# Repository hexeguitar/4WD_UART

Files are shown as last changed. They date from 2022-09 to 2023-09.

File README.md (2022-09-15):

# 4WD UART
### CH344Q based quad isolated USB-UART interface with ESP programmer. 
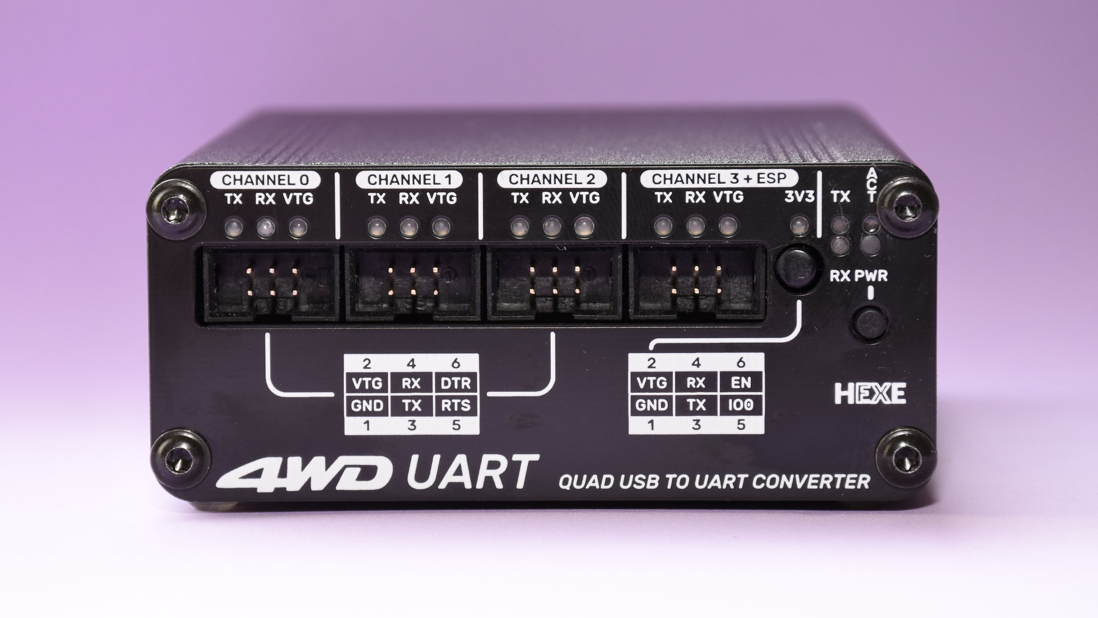
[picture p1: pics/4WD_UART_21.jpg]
 
### Features | Specs 
* 4 fully isolated channels  
  * Channel 0 - 2: classic UART with TX, RX, DTR and RTS signals
  * Channel 3: UART + ESP8266/ESP32 programmer signals (EN + IO0) and isolated 3.3V supply  
* individual TX/RX activity indicators per channel  
* theoretical max baud rate per channel: 6Mbps (tested up to 4.5Mbps on Linux)
* target voltage range: 3V - 5V (required for the isolators)
* USB C for power and data
* optional soft power switch (hold to power on/off) or regular toggle one
* USB inrush current limiter

<table>
  <tr>
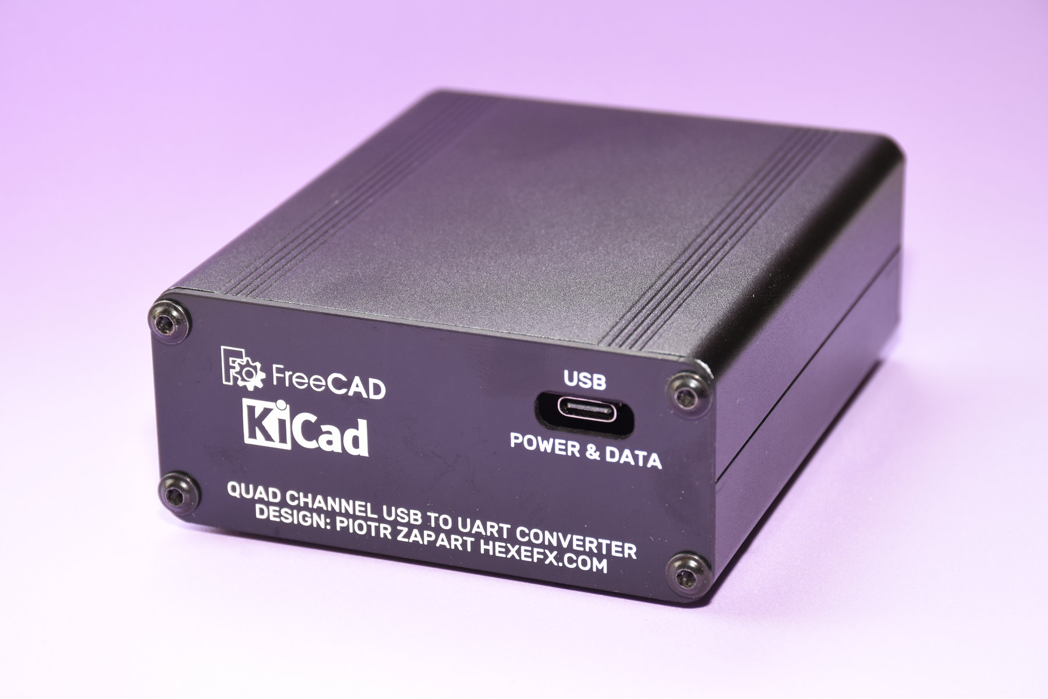
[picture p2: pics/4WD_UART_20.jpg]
rear view
    <td> </td>
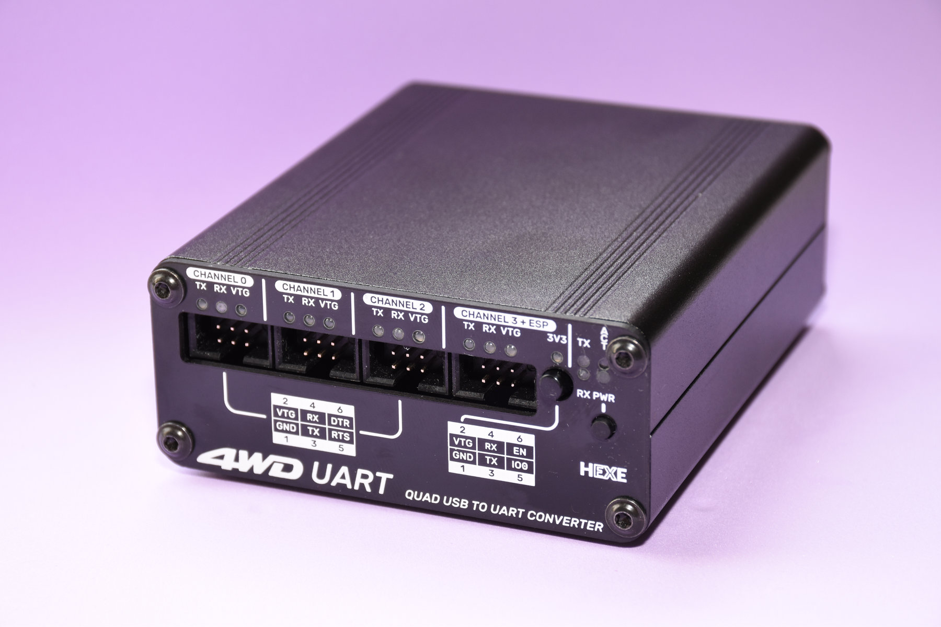
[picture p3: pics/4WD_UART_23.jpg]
4WD UART
    <td> </td>
  </tr>  
</table>  

### Leds  
Per channel:
* TX, RX - activity leds
* VTG - target power presence  

For channel 3:
* 3V3 - internal isolated 3.3V supply enable  

Global:
* TX, RX - global CH344Q activity leds
* ACT - USB enumeration success
* PWR - power indicator

### Electronic design  
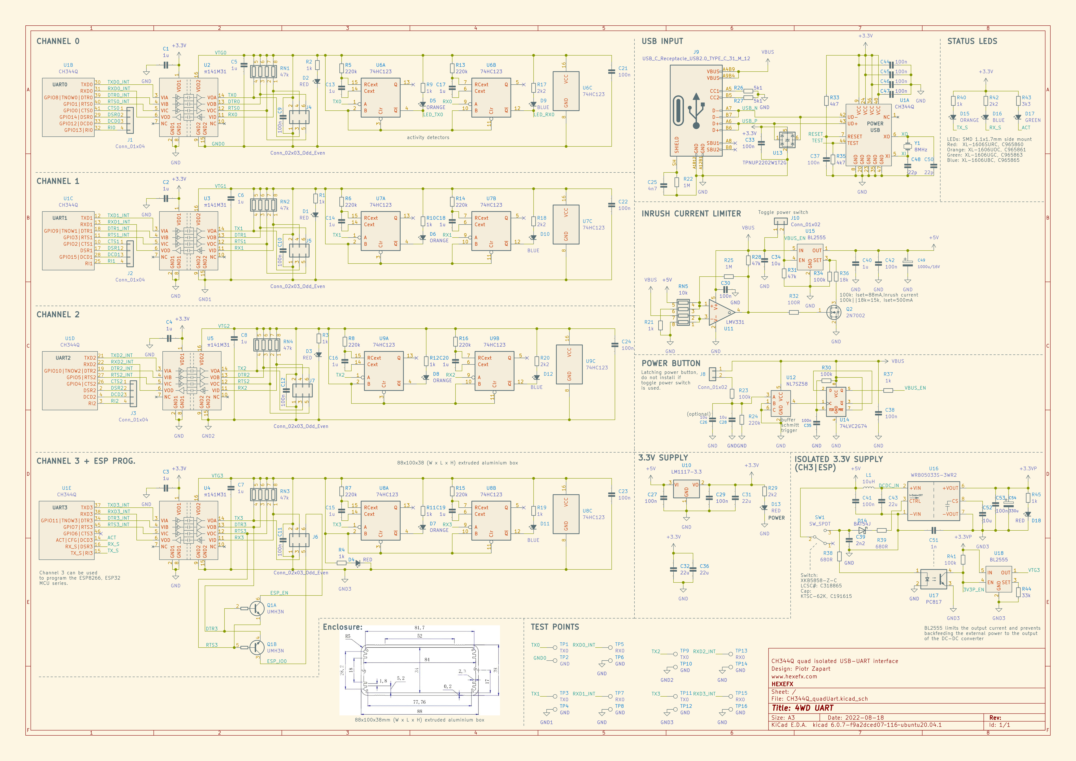
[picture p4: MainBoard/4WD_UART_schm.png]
 
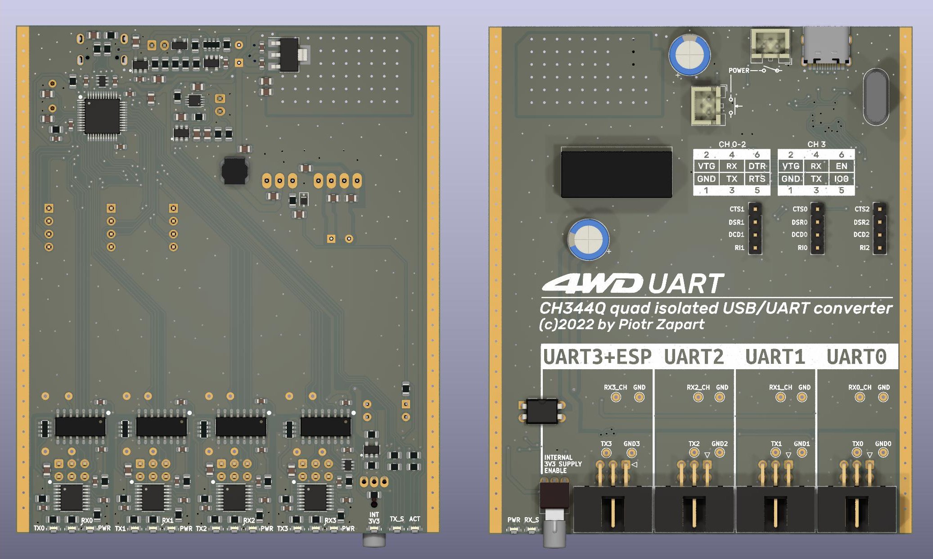
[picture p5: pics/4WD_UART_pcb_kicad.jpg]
 

### Mechanical design  
PCB is designed to slide into an 88x100x38mm aluminium extruded enclosure. Front panel and back panel PCBs replace the original plates.  
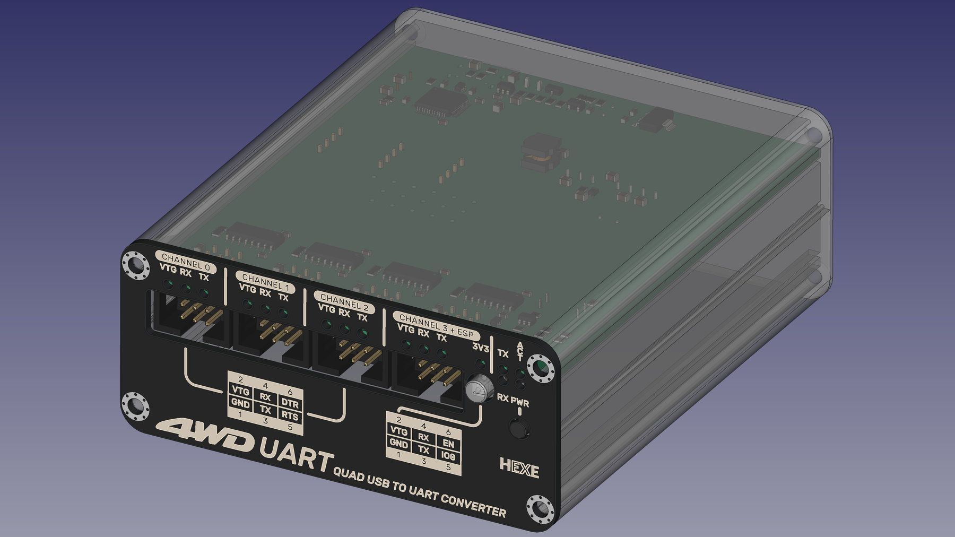
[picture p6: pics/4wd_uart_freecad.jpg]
 
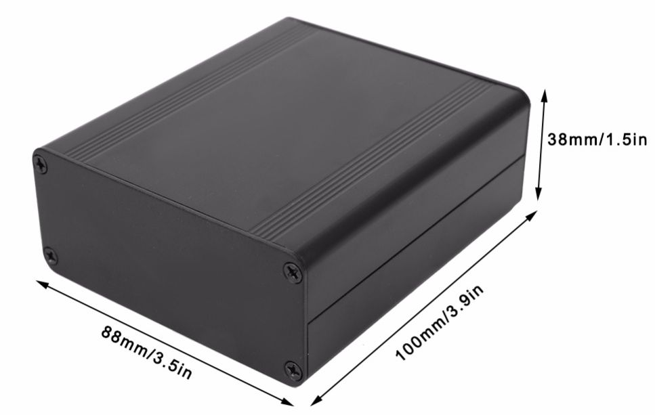
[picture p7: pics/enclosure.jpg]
 

### Front panel  
Front panel is designed to accommodate the version with soft power switch. A normal pushbutton is used, but installed in reverse with terminals bent, as shown on the pic:  
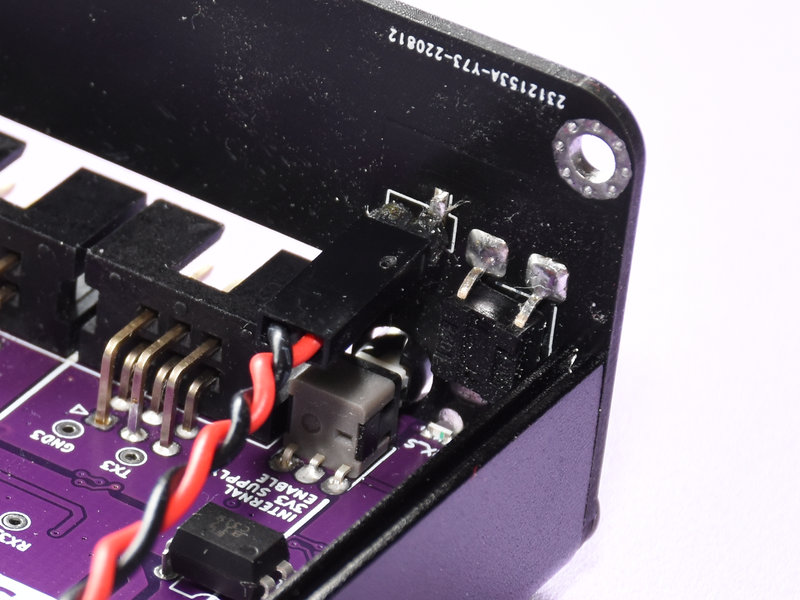
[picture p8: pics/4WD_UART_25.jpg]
  
A single 1x02 0.1" SMD type pin header is used to connect the pushbutton to the main board.  
Light pipes for the leds can be made by pushing a tiny bit of hot glue into the holes.  

### Operation  
For most modern operating systems the device does not require any special drivers and should be detected automatically.  
On Linux 4WD UART is reporting as 4 /dev/TTYACMx devices:  
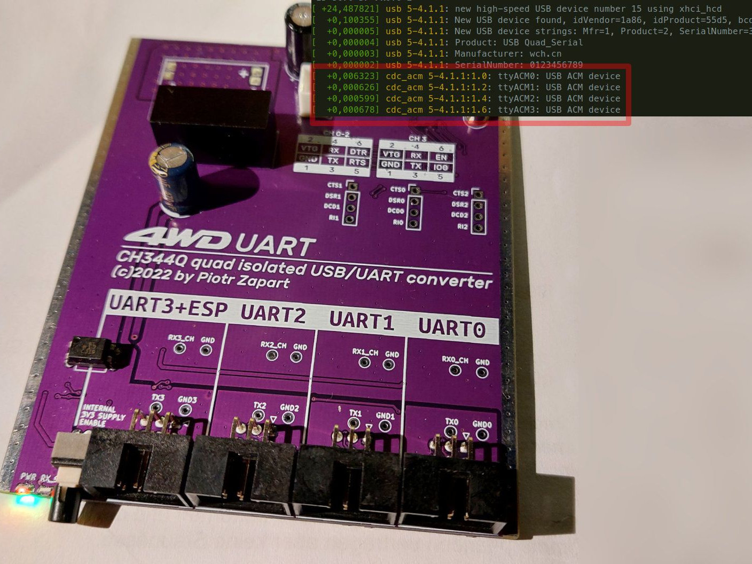
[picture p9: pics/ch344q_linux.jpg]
  

___
## All channels except 3 (if 3V3 is enabled) require external power supply in range from 3V to 5V to operate the output digital isolators and do the level shifting.  

Copyright (c) 2022 by Piotr Zapart  
www.hexefx.com  

## License
  
This work is licensed under a [Creative Commons Attribution-ShareAlike 3.0 International License][cc-by-sa].  

[cc-by-sa]: http://creativecommons.org/licenses/by-sa/3.0/
[cc-by-sa-image]: https://licensebuttons.net/l/by-sa/3.0/88x31.png
[cc-by-sa-shield]: https://img.shields.io/badge/License-CC%20BY--SA%203.0-lightgrey.svg

[main_pic]: pics/4WD_UART_21.jpg "4WD UART front view"
[rear_view]: pics/4WD_UART_20.jpg "rear view"
[iso_view]: pics/4WD_UART_23.jpg "4WD UART"
[schematic]: MainBoard/4WD_UART_schm.png "4WD UART schematic"
[pcb]: pics/4WD_UART_pcb_kicad.jpg "4WD UART pcb"
[mech1]: pics/4wd_uart_freecad.jpg "4WD UART enclosure"
[mech2]: pics/enclosure.jpg "4WD UART enclosure"
[panel1]: pics/4WD_UART_25.jpg "4WD UART enclosure"  
[linux]: pics/ch344q_linux.jpg "4WD UART enclosure"

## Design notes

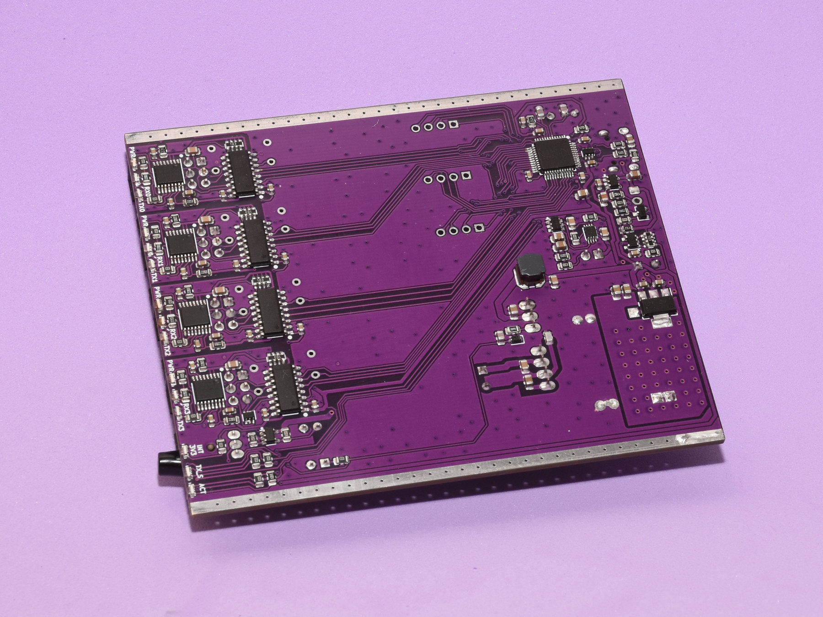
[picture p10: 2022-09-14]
pics/4WD_UART_24.jpg

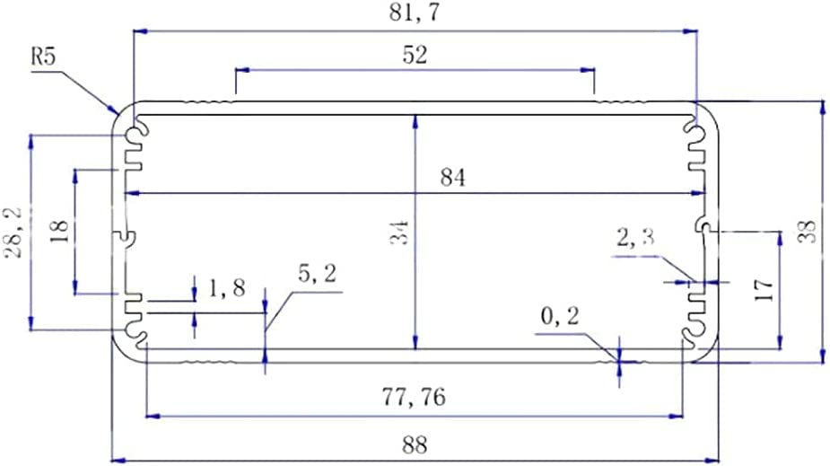
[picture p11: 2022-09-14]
pics/88x100x38_aluBox.jpg

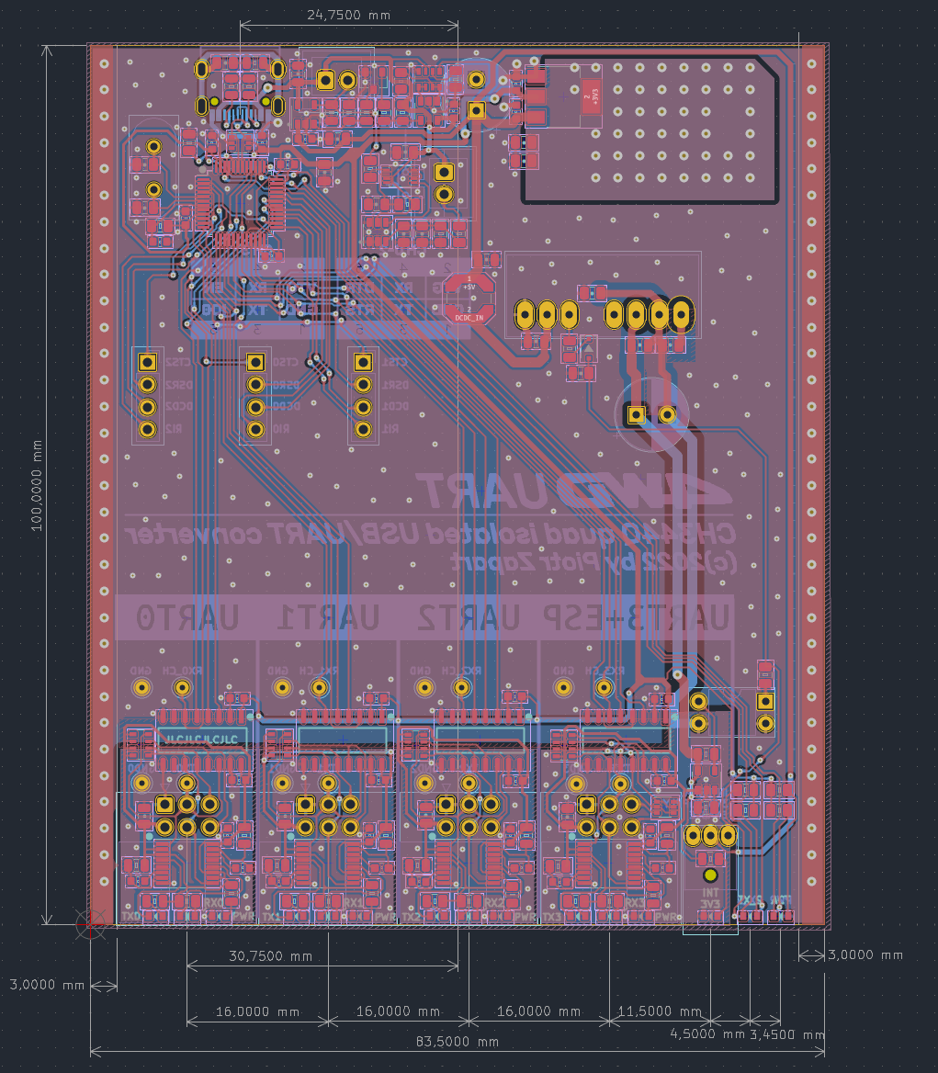
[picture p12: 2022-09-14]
pics/4WD_UART_pcb_dim.png

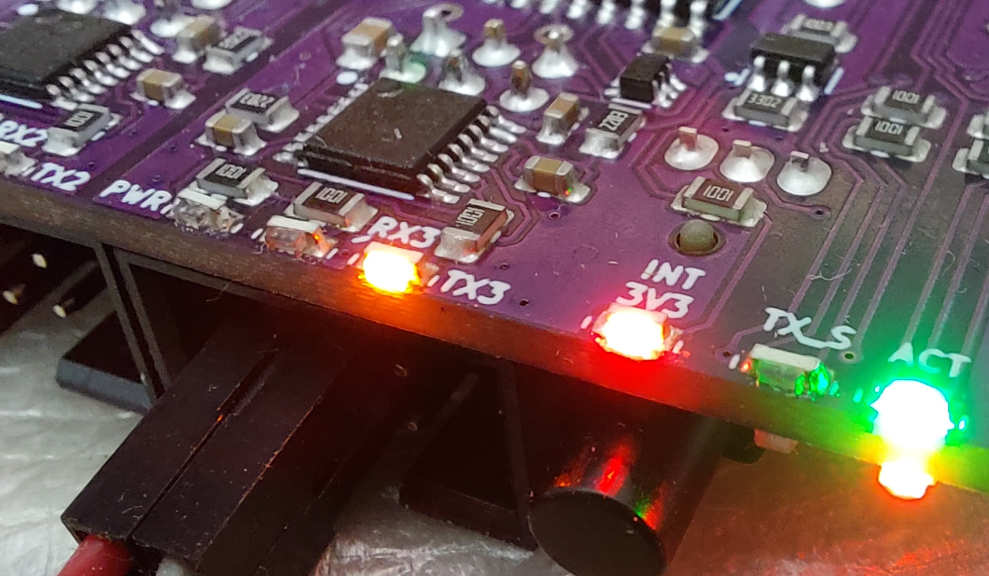
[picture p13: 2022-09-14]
pics/4WD_UART_18.jpg

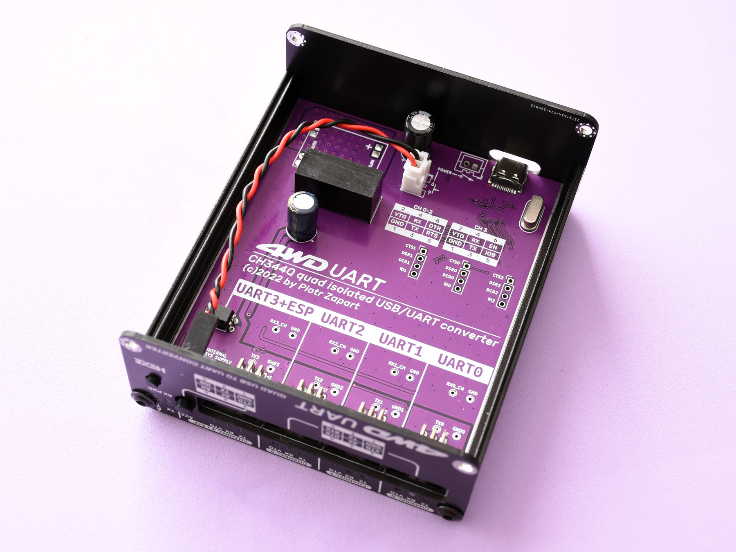
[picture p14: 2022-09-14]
pics/4WD_UART_22.jpg

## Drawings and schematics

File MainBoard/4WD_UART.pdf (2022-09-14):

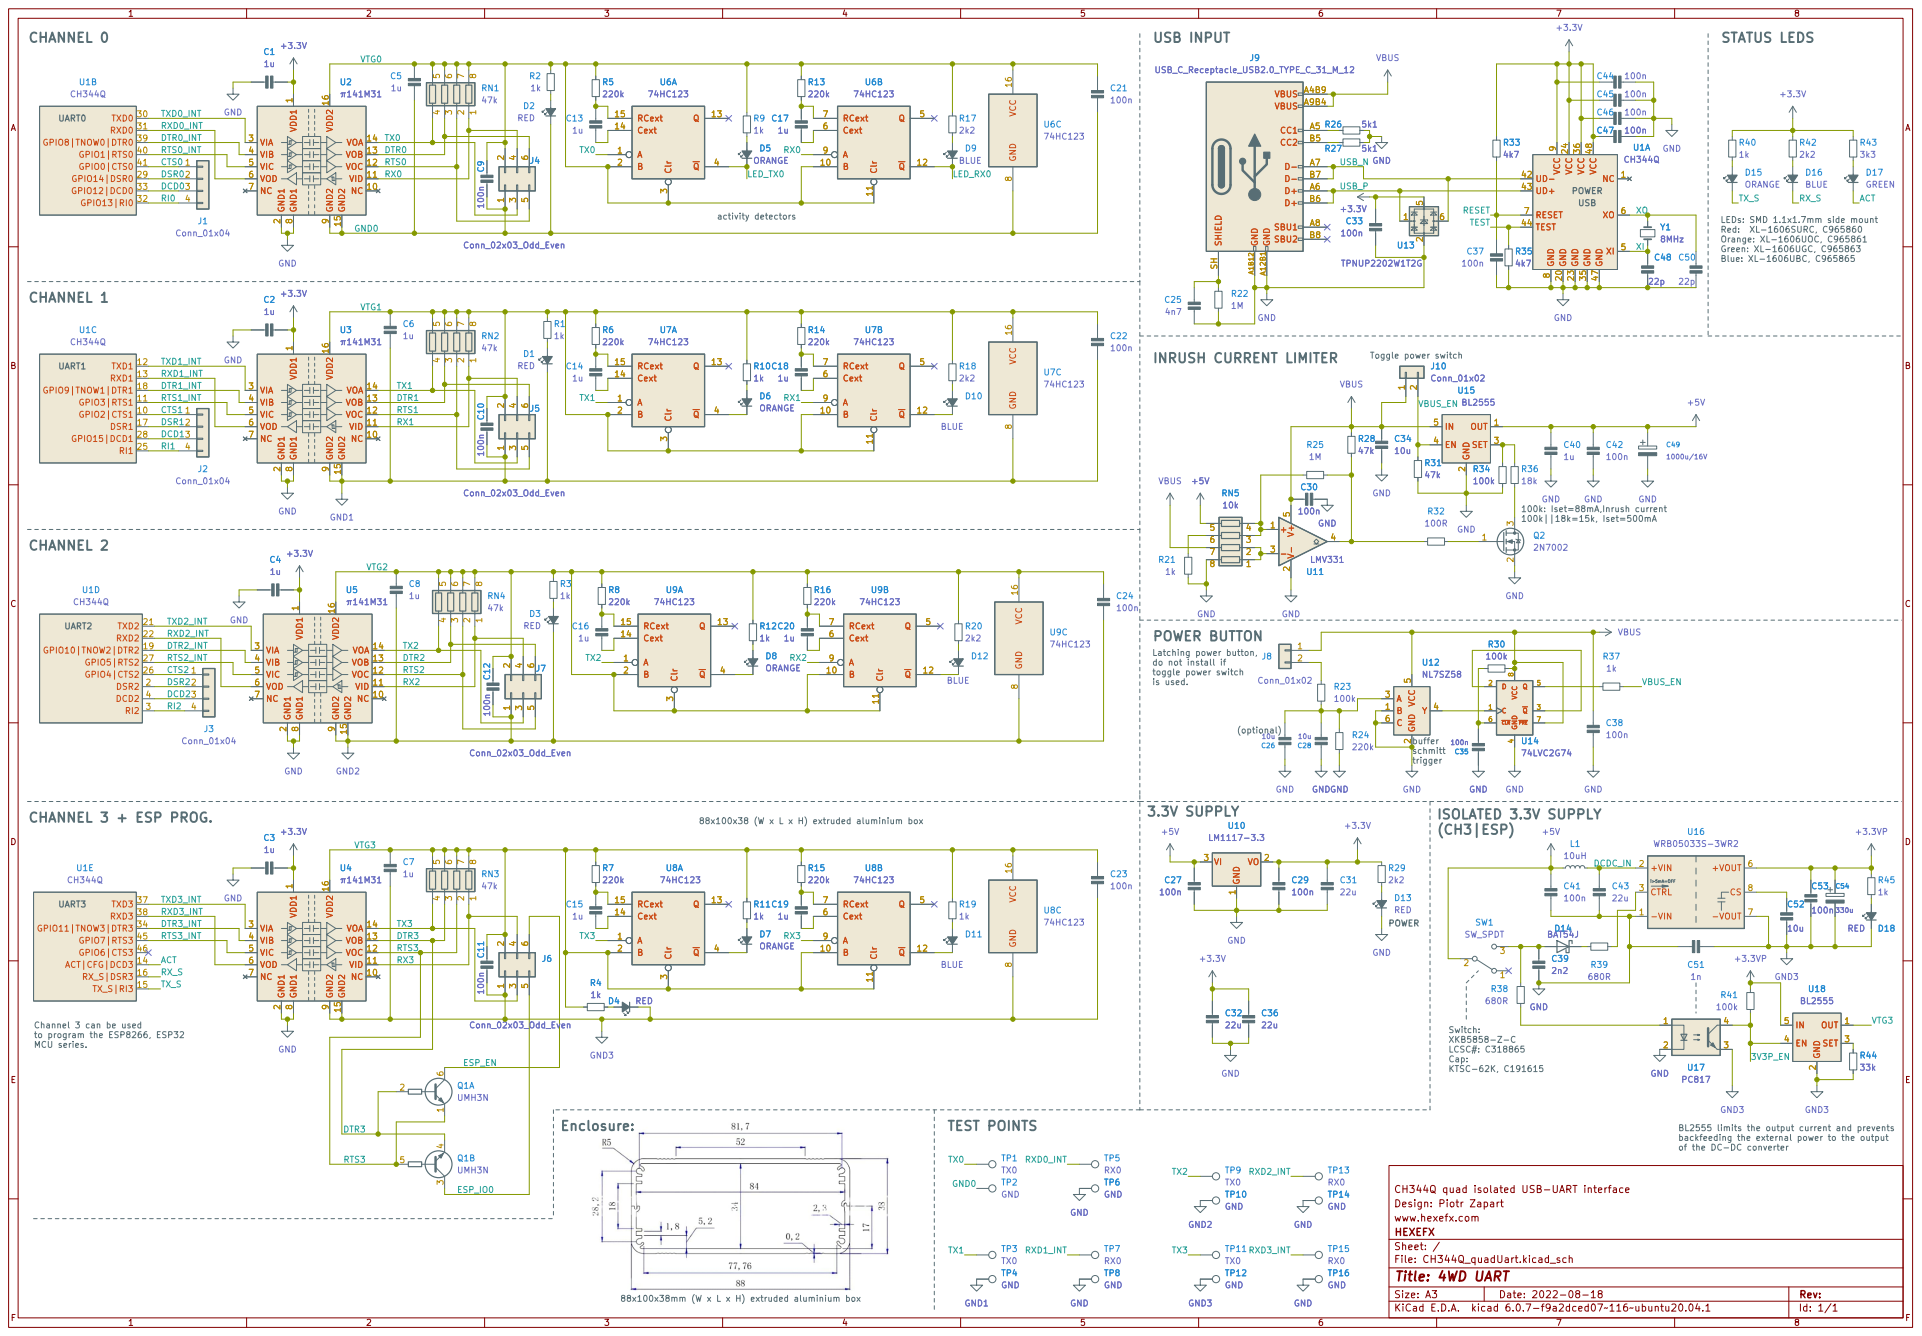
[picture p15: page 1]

1 NC 10 VID 11 VOC 12 VOB 13 VOA 14 GND2 15 VDD2 16 GND1

2 VIA 3 VIB 4 VIC 5 VOD 6 NC 7 GND1

LEDs: SMD 1.1x1.7mm side mount Red: XL-1606SURC, C965860 Orange: XL-1606UOC, C965861 Green: XL-1606UGC, C965863 Blue: XL-1606UBC, C965865 U5

TX1 RX3 VTG3

Toggle power switch INRUSH CURRENT LIMITER

Latching power button, do not install if

88x100x38 (W x L x H) extruded aluminium box Channel 3 can be used

to program the ESP8266, ESP32 MCU series.

BL2555 limits the output current and prevents
backfeeding the external power to the output of the DC-DC converter

CH344Q quad isolated USB-UART interface
Design: Piotr Zapart
File: CH344Q_quadUart.kicad_sch Sheet: / HEXEFX www.hexefx.com

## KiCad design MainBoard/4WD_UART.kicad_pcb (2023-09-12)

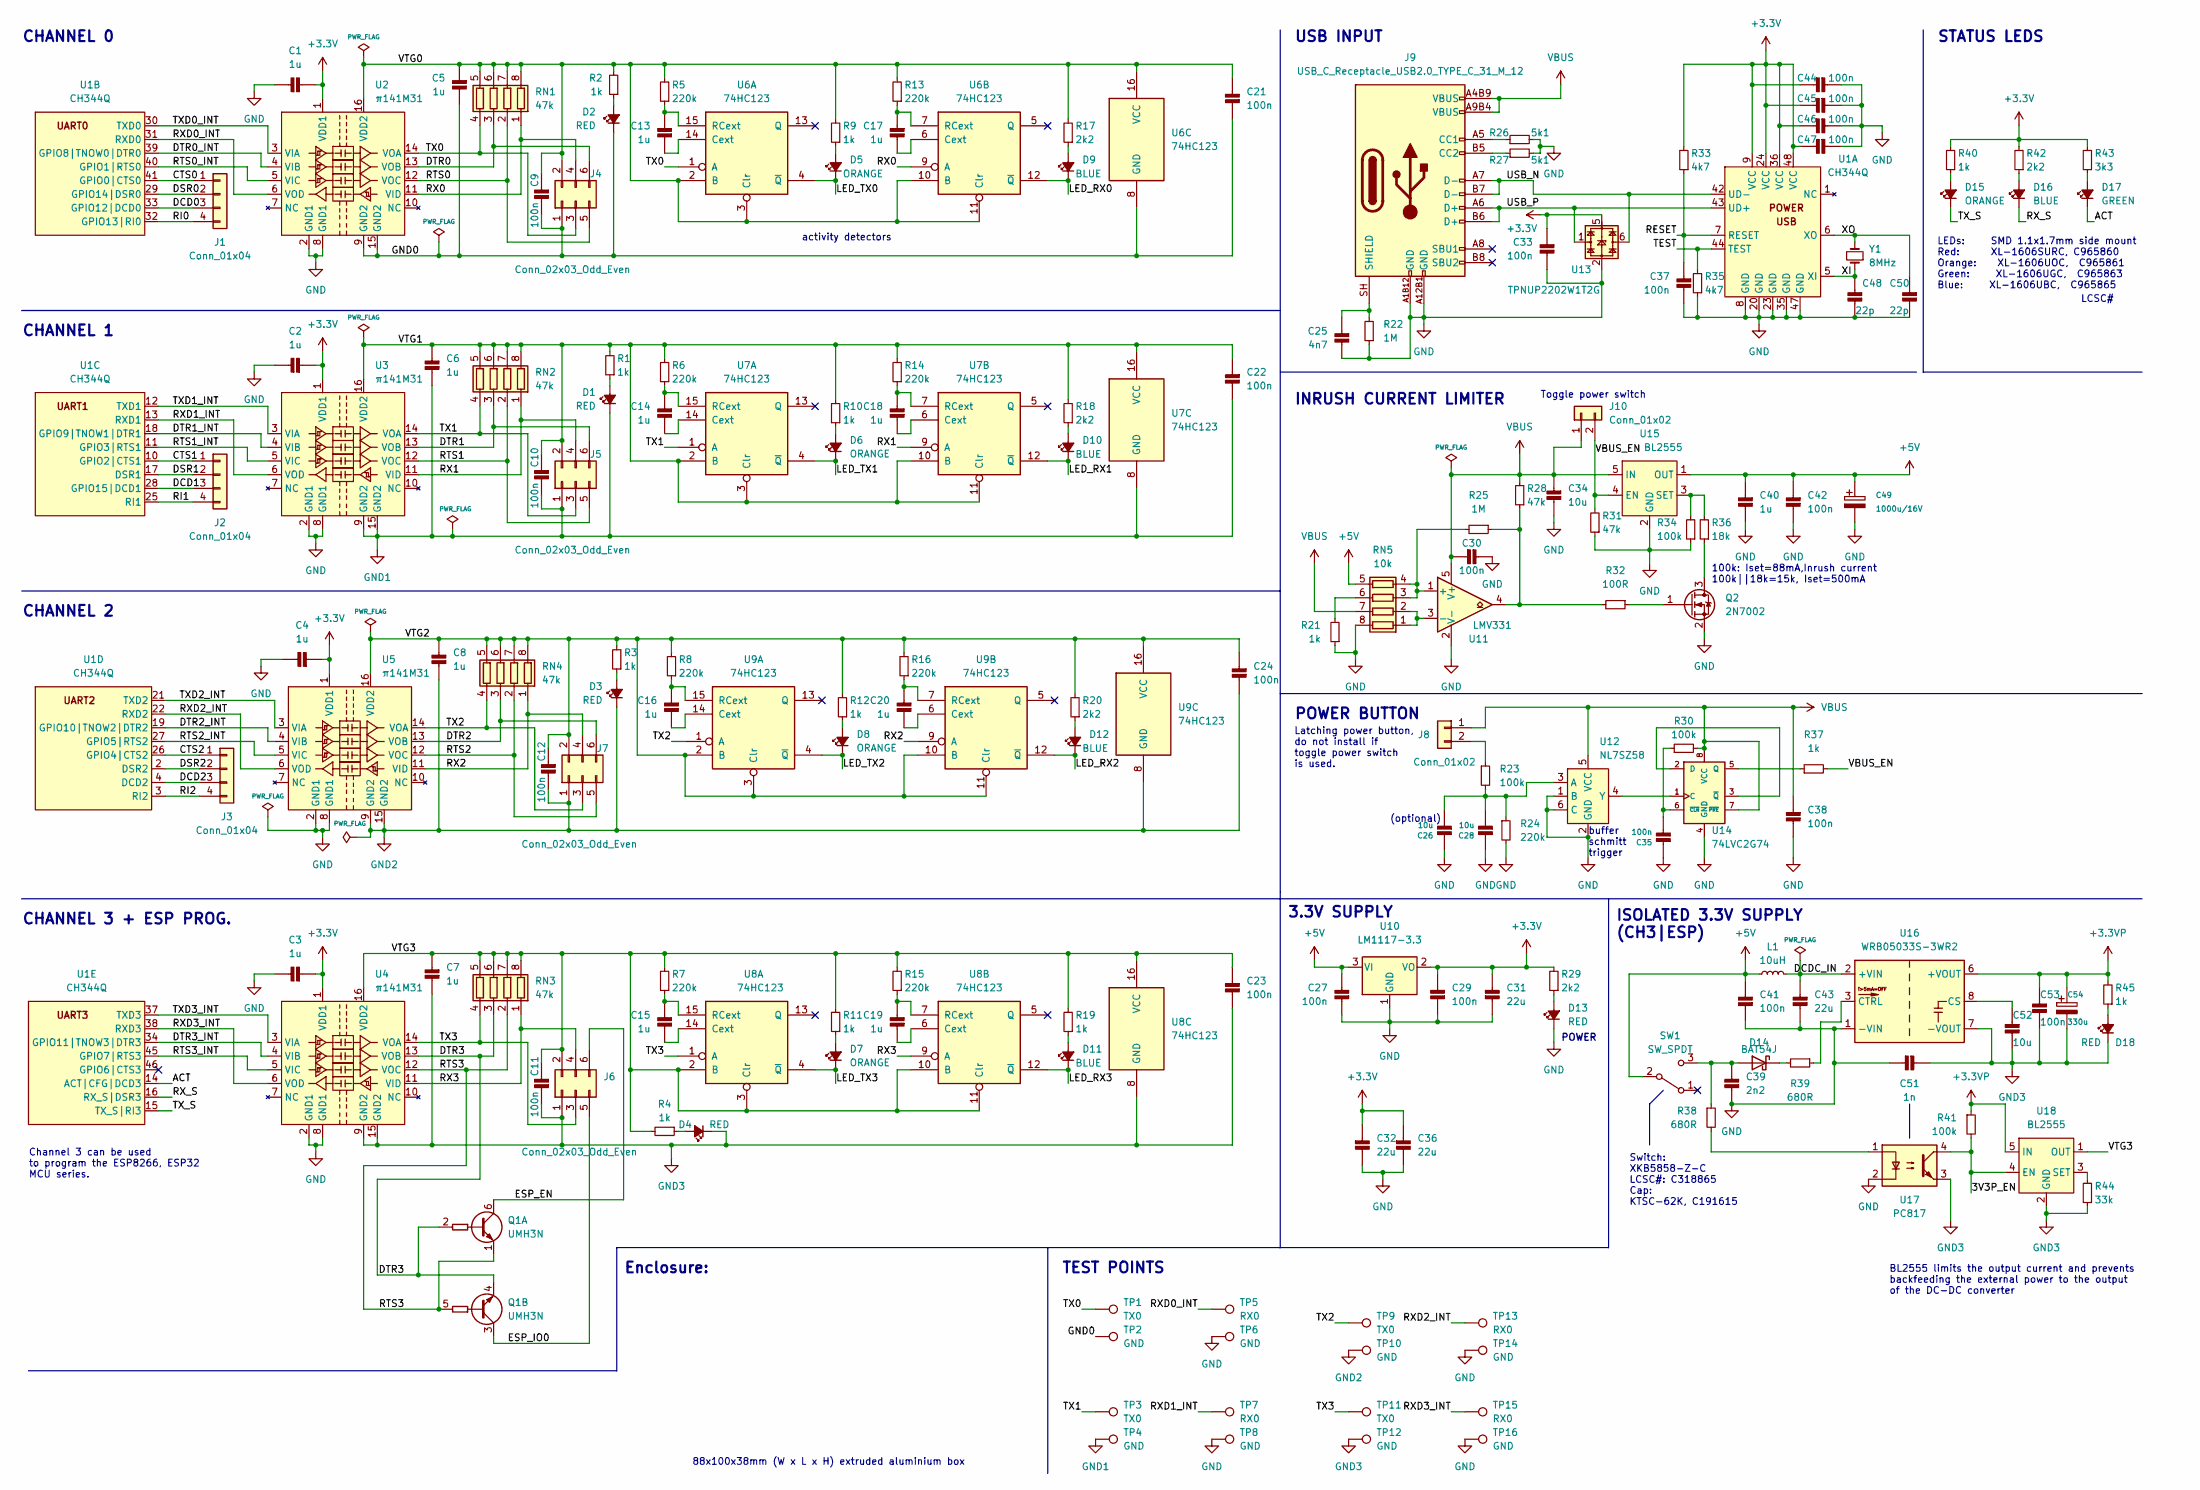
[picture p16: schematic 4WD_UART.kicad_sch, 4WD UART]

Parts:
C1, C2, C3, C4, C5, C6, C7, C8, C13, C14, C15, C16, C17, C18, C19, C20: 1u; Hx_C_0603_1608Metric
C9, C10, C11, C12, C35, C38, C41, C53: 100n; Hx_C_0805_2012Metric
C21, C22, C23, C24, C27, C29, C30, C33, C37, C42, C44, C45, C46, C47: 100n; Hx_C_0603_1608Metric
C25: 4n7; Hx_C_0805_2012Metric
C26, C28, C34, C52: 10u; Hx_C_0805_2012Metric
C31, C32, C36, C43: 22u; Hx_C_0805_2012Metric
C39: 2n2; Hx_C_0805_2012Metric
C40: 1u; Hx_C_0805_2012Metric
C48, C50: 22p; Hx_C_0805_2012Metric
C49: 1000u/16V; CP_Radial_D8.0mm_P3.50mm
C51: 1n; Hx_C_0805_2012Metric
C54: 330u; CP_Radial_D8.0mm_P3.50mm
D1, D2, D3, D4, D13, D18: RED; XL-1606_SMD side LED 1.7x1.1x0.6mm
D5, D6, D7, D8, D15: ORANGE; XL-1606_SMD side LED 1.7x1.1x0.6mm
D9, D10, D11, D12, D16: BLUE; XL-1606_SMD side LED 1.7x1.1x0.6mm
D14: BAT54J; D_SOD-323F
D17: GREEN; XL-1606_SMD side LED 1.7x1.1x0.6mm
J1, J2, J3: Conn_01x04; PinHeader_1x04_P2.54mm_Vertical
J4, J5, J6, J7: Conn_02x03_Odd_Even; IDC-Header_2x03_P2.54mm_Horizontal
J8, J10: Conn_01x02; JST_XA_B02B-XASK-1_1x02_P2.50mm_Vertical
J9: USB_C_Receptacle_USB2.0_TYPE_C_31_M_12; USB_C_TYPE-C-31-M-12; LCSC C283540
L1: 10uH; L_Coilcraft_LPS5030
Q1: UMH3N; SOT-363_SC-70-6
Q2: 2N7002; SOT-23
R1, R2, R3, R4, R9, R10, R11, R12, R19, R21, R37, R40, R45: 1k; Hx_R_0805_2012Metric
R5, R6, R7, R8, R13, R14, R15, R16, R24: 220k; Hx_R_0805_2012Metric
R17, R18, R20, R29, R42: 2k2; Hx_R_0805_2012Metric
R22, R25: 1M; Hx_R_0805_2012Metric
R23, R30, R34, R41: 100k; Hx_R_0805_2012Metric
R26, R27: 5k1; Hx_R_0805_2012Metric
R28, R31: 47k; Hx_R_0805_2012Metric
R32: 100R; Hx_R_0805_2012Metric
R33, R35: 4k7; Hx_R_0805_2012Metric
R36: 18k; Hx_R_0805_2012Metric
R38, R39: 680R; Hx_R_0805_2012Metric
R43: 3k3; Hx_R_0805_2012Metric
R44: 33k; Hx_R_0805_2012Metric
RN1, RN2, RN3, RN4: 47k; R_Array_Convex_4x0603
RN5: 10k; R_Array_Convex_4x0603
SW1: SW_SPDT; XKB5858-X-C_SPDT_PCB_angle_switch
TP1, TP3, TP9, TP11: TX0; TestPoint_THTPad_D1.5mm_Drill0.7mm
TP2, TP4, TP6, TP8, TP10, TP12, TP14, TP16: GND; TestPoint_THTPad_D1.5mm_Drill0.7mm
TP5, TP7, TP13, TP15: RX0; TestPoint_THTPad_D1.5mm_Drill0.7mm
U1: CH344Q; LQFP-48_7x7mm_P0.5mm; LCSC C2988084
U2, U3, U4, U5: π141M31; SOIC16; LCSC C471605
U6, U7, U8, U9: 74HC123; TSSOP-16_4.4x5mm_P0.65mm
U10: LM1117-3.3; SOT-223-3_TabPin2
U11: LMV331; SOT-23-5; LCSC C107643
U12: NL7SZ58; SOT-23-6
U13: TPNUP2202W1T2G; SOT-363_SC-70-6; LCSC C2959847
U14: 74LVC2G74; VSSOP-8_2.4x2.1mm_P0.5mm
U15, U18: BL2555; SOT-23-5; LCSC C2838883
U16: WRB05033S-3WR2; WRBD5xx5_3WR2
U17: PC817; DIP-4_W7.62mm
Y1: 8MHz; Crystal_HC49-U_Vertical

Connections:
+3.3VP: C53.2, C54.1, R41.1, R45.2, U16.6 (+VOUT), U18.5 (IN)
+3V3: C1.2, C2.2, C3.2, C4.2, C29.2, C31.2, C32.2, C33.2, C36.2, C44.2, C45.2, C46.2, C47.2, R29.2, R33.2, R40.2, R42.2, R43.2, U1.9 (VCC), U1.24 (VCC), U1.36 (VCC), U1.48 (VCC), U2.1 (VDD1), U3.1 (VDD1), U4.1 (VDD1), U5.1 (VDD1), U10.2 (VO), U13.5
+5V: C27.2, C40.2, C41.2, C42.2, C49.1, L1.1, RN5.5 (R4.2), SW1.2 (B), U10.3 (VI), U15.1 (OUT)
/3V3P_EN: R41.2, U17.4, U18.4 (EN)
/ACT: D17.1 (K), U1.14 (ACT|CFG|DCD3)
/CTS0: J1.1, U1.41 (GPIO0|CTS0)
/CTS1: J2.1, U1.10 (GPIO2|CTS1)
/CTS2: J3.1, U1.26 (GPIO4|CTS2)
/DCD0: J1.3, U1.33 (GPIO12|DCD0)
/DCD1: J2.3, U1.28 (GPIO15|DCD1)
/DCD2: J3.3, U1.4 (DCD2)
/DCDC_IN: C43.2, L1.2, U16.2 (+VIN)
/DSR0: J1.2, U1.29 (GPIO14|DSR0)
/DSR1: J2.2, U1.17 (DSR1)
/DSR2: J3.2, U1.2 (DSR2)
/DTR0: J4.6, RN1.3 (R3.1), U2.13 (VOB)
/DTR0_INT: U1.39 (GPIO8|TNOW0|DTR0), U2.4 (VIB)
/DTR1: J5.6, RN2.3 (R3.1), U3.13 (VOB)
/DTR1_INT: U1.18 (GPIO9|TNOW1|DTR1), U3.4 (VIB)
/DTR2: J7.6, RN4.3 (R3.1), U5.13 (VOB)
/DTR2_INT: U1.19 (GPIO10|TNOW2|DTR2), U5.4 (VIB)
/DTR3: Q1.2 (B1), Q1.4 (E2), RN3.3 (R3.1), U4.13 (VOB)
/DTR3_INT: U1.34 (GPIO11|TNOW3|DTR3), U4.4 (VIB)
/ESP_EN: J6.6, Q1.6 (C1)
/ESP_IO0: J6.5, Q1.3 (C2)
/GND0: C5.1, C9.1, C21.1, D2.1 (K), J4.1, TP2.1, U2.9 (GND2), U2.15 (GND2), U6.8 (GND)
/LED_RX0: D9.1 (K), U6.12 (~Q)
/LED_RX1: D10.1 (K), U7.12 (~Q)
/LED_RX2: D12.1 (K), U9.12 (~Q)
/LED_RX3: D11.1 (K), U8.12 (~Q)
/LED_TX0: D5.1 (K), U6.4 (~Q)
/LED_TX1: D6.1 (K), U7.4 (~Q)
/LED_TX2: D8.1 (K), U9.4 (~Q)
/LED_TX3: D7.1 (K), U8.4 (~Q)
/RESET: C37.2, R33.1, U1.7 (RESET)
/RI0: J1.4, U1.32 (GPIO13|RI0)
/RI1: J2.4, U1.25 (RI1)
/RI2: J3.4, U1.3 (RI2)
/RTS0: J4.5, RN1.2 (R2.1), U2.12 (VOC)
/RTS0_INT: U1.40 (GPIO1|RTS0), U2.5 (VIC)
/RTS1: J5.5, RN2.2 (R2.1), U3.12 (VOC)
/RTS1_INT: U1.11 (GPIO3|RTS1), U3.5 (VIC)
/RTS2: J7.5, RN4.2 (R2.1), U5.12 (VOC)
/RTS2_INT: U1.27 (GPIO5|RTS2), U5.5 (VIC)
/RTS3: Q1.1 (E1), Q1.5 (B2), RN3.2 (R2.1), U4.12 (VOC)
/RTS3_INT: U1.45 (GPIO7|RTS3), U4.5 (VIC)
/RX0: J4.4, RN1.1 (R1.1), U2.11 (VID), U6.9 (A)
/RX1: J5.4, RN2.1 (R1.1), U3.11 (VID), U7.9 (A)
/RX2: J7.4, RN4.1 (R1.1), U5.11 (VID), U9.9 (A)
/RX3: J6.4, RN3.1 (R1.1), U4.11 (VID), U8.9 (A)
/RXD0_INT: TP5.1, U1.31 (RXD0), U2.6 (VOD)
/RXD1_INT: TP7.1, U1.13 (RXD1), U3.6 (VOD)
/RXD2_INT: TP13.1, U1.22 (RXD2), U5.6 (VOD)
/RXD3_INT: TP15.1, U1.38 (RXD3), U4.6 (VOD)
/RX_S: D16.1 (K), U1.16 (RX_S|DSR3)
/TEST: R35.2, U1.44 (TEST)
/TX0: J4.3, RN1.4 (R4.1), TP1.1, U2.14 (VOA), U6.1 (A)
/TX1: J5.3, RN2.4 (R4.1), TP3.1, U3.14 (VOA), U7.1 (A)
/TX2: J7.3, RN4.4 (R4.1), TP9.1, U5.14 (VOA), U9.1 (A)
/TX3: J6.3, RN3.4 (R4.1), TP11.1, U4.14 (VOA), U8.1 (A)
/TXD0_INT: U1.30 (TXD0), U2.3 (VIA)
/TXD1_INT: U1.12 (TXD1), U3.3 (VIA)
/TXD2_INT: U1.21 (TXD2), U5.3 (VIA)
/TXD3_INT: U1.37 (TXD3), U4.3 (VIA)
/TX_S: D15.1 (K), U1.15 (TX_S|RI3)
/USB_N: J9.A7 (D-), J9.B7 (D-), U1.42 (UD-), U13.6
/USB_P: J9.A6 (D+), J9.B6 (D+), U1.43 (UD+), U13.1
/VBUS_EN: J10.2, R31.2, R37.2, U15.4 (EN)
/VTG0: C5.2, C9.2, C21.2, J4.2, R2.2, R5.2, R9.2, R13.2, R17.2, RN1.5 (R4.2), RN1.6 (R3.2), RN1.7 (R2.2), RN1.8 (R1.2), U2.16 (VDD2), U6.2 (B), U6.3 (Clr), U6.10 (B), U6.11 (Clr), U6.16 (VCC)
/VTG1: C6.2, C10.2, C22.2, J5.2, R1.2, R6.2, R10.2, R14.2, R18.2, RN2.5 (R4.2), RN2.6 (R3.2), RN2.7 (R2.2), RN2.8 (R1.2), U3.16 (VDD2), U7.2 (B), U7.3 (Clr), U7.10 (B), U7.11 (Clr), U7.16 (VCC)
/VTG2: C8.2, C12.2, C24.2, J7.2, R3.2, R8.2, R12.2, R16.2, R20.2, RN4.5 (R4.2), RN4.6 (R3.2), RN4.7 (R2.2), RN4.8 (R1.2), U5.16 (VDD2), U9.2 (B), U9.3 (Clr), U9.10 (B), U9.11 (Clr), U9.16 (VCC)
/VTG3: C7.2, C11.2, C23.2, J6.2, R4.2, R7.2, R11.2, R15.2, R19.2, RN3.5 (R4.2), RN3.6 (R3.2), RN3.7 (R2.2), RN3.8 (R1.2), U4.16 (VDD2), U8.2 (B), U8.3 (Clr), U8.10 (B), U8.11 (Clr), U8.16 (VCC), U18.1 (OUT)
/XI: C48.2, U1.5 (XI), Y1.1
/XO: C50.2, U1.6 (XO), Y1.2
GND: C1.1, C2.1, C3.1, C4.1, C25.1, C26.2, C27.1, C28.2, C29.1, C30.1, C31.1, C32.1, C33.1, C34.1, C35.2, C36.1, C37.1, C38.1, C39.1, C40.1, C41.1, C42.1, C43.1, C44.1, C45.1, C46.1, C47.1, C48.1, C49.2, C50.1, C51.2, D13.1 (K), J9.A1B12 (GND), J9.A12B1 (GND), Q2.2 (S), R21.1, R22.1, R24.2, R26.2, R27.2, R31.1, R34.1, R35.1, RN5.8 (R1.2), TP6.1, TP8.1, TP14.1, TP16.1, U1.8 (GND), U1.20 (GND), U1.23 (GND), U1.35 (GND), U1.47 (GND), U2.2 (GND1), U2.8 (GND1), U3.2 (GND1), U3.8 (GND1), U4.2 (GND1), U4.8 (GND1), U5.2 (GND1), U5.8 (GND1), U10.1 (GND), U11.2 (V-), U12.1 (B), U12.2 (GND), U12.6 (C), U13.2, U14.4 (GND), U15.2 (GND), U16.1 (-VIN), U17.2
GND1: C6.1, C10.1, C22.1, D1.1 (K), J5.1, TP4.1, U3.9 (GND2), U3.15 (GND2), U7.8 (GND)
GND2: C8.1, C12.1, C24.1, D3.1 (K), J7.1, TP10.1, U5.9 (GND2), U5.15 (GND2), U9.8 (GND)
GND3: C7.1, C11.1, C23.1, C51.1, C52.1, C53.1, C54.2, D4.1 (K), D18.1 (K), J6.1, R44.1, TP12.1, U4.9 (GND2), U4.15 (GND2), U8.8 (GND), U16.7 (-VOUT), U17.3, U18.2 (GND)
unnamed: C13.1, U6.14 (Cext)
unnamed: C13.2, R5.1, U6.15 (RCext)
unnamed: C14.1, U7.14 (Cext)
unnamed: C14.2, R6.1, U7.15 (RCext)
unnamed: C15.1, U8.14 (Cext)
unnamed: C15.2, R7.1, U8.15 (RCext)
unnamed: C16.1, U9.14 (Cext)
unnamed: C16.2, R8.1, U9.15 (RCext)
unnamed: C17.1, U6.6 (Cext)
unnamed: C17.2, R13.1, U6.7 (RCext)
unnamed: C18.1, U7.6 (Cext)
unnamed: C18.2, R14.1, U7.7 (RCext)
unnamed: C19.1, U8.6 (Cext)
unnamed: C19.2, R15.1, U8.7 (RCext)
unnamed: C20.1, U9.6 (Cext)
unnamed: C20.2, R16.1, U9.7 (RCext)
unnamed: C25.2, J9.SH (SHIELD), R22.2
unnamed: C26.1, C28.1, R23.2, R24.1, U12.3 (A)
unnamed: C35.1, R30.1, U14.6 (~CLR)
unnamed: C39.2, D14.2 (A), R38.1, SW1.3 (C)
unnamed: C52.2, U16.8 (CS)
unnamed: D1.2 (A), R1.1
unnamed: D2.2 (A), R2.1
unnamed: D3.2 (A), R3.1
unnamed: D4.2 (A), R4.1
unnamed: D5.2 (A), R9.1
unnamed: D6.2 (A), R10.1
unnamed: D7.2 (A), R11.1
unnamed: D8.2 (A), R12.1
unnamed: D9.2 (A), R17.1
unnamed: D10.2 (A), R18.1
unnamed: D11.2 (A), R19.1
unnamed: D12.2 (A), R20.1
unnamed: D13.2 (A), R29.1
unnamed: D14.1 (K), R39.2
unnamed: D15.2 (A), R40.1
unnamed: D16.2 (A), R42.1
unnamed: D17.2 (A), R43.1
unnamed: D18.2 (A), R45.1
unnamed: J8.2, R23.1
unnamed: J9.A5 (CC1), R26.1
unnamed: J9.B5 (CC2), R27.1
unnamed: Q2.1 (G), R32.1
unnamed: Q2.3 (D), R36.1
unnamed: R21.2, RN5.6 (R3.2)
unnamed: R25.1, R28.1, R32.2, U11.4
unnamed: R25.2, RN5.3 (R3.1), RN5.4 (R4.1), U11.1 (+)
unnamed: R34.2, R36.2, U15.3 (SET)
unnamed: R37.1, U14.5 (Q)
unnamed: R38.2, U17.1
unnamed: R39.1, U16.3 (CTRL)
unnamed: R44.2, U18.3 (SET)
unnamed: RN5.1 (R1.1), RN5.2 (R2.1), U11.3 (-)
unnamed: U12.4 (Y), U14.1 (C)
unnamed: U14.2 (D), U14.3 (~Q)
VBUS: C30.2, C34.2, C38.2, J8.1, J9.A4B9 (VBUS), J9.A9B4 (VBUS), J10.1, R28.2, R30.2, RN5.7 (R2.2), U11.5 (V+), U12.5 (VCC), U14.7 (~PRE), U14.8 (VCC), U15.5 (IN)

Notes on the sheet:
TEST POINTS
Latching power button, do not install if toggle power switch is used.
BL2555 limits the output current and prevents backfeeding the external power to the output of the DC-DC converter
buffer schmitt trigger
INRUSH CURRENT LIMITER
88x100x38mm (W x L x H) extruded aluminium box
POWER BUTTON
Switch: XKB5858-Z-C LCSC#: C318865 Cap: KTSC-62K, C191615
3.3V SUPPLY
(optional)
100k: Iset=88mA,Inrush current 100k||18k=15k, Iset=500mA
STATUS LEDS
CHANNEL 3 + ESP PROG.
CHANNEL 1
LCSC#
POWER
Toggle power switch
activity detectors
Channel 3 can be used to program the ESP8266, ESP32 MCU series.
Enclosure:
CHANNEL 2
LEDs: SMD 1.1x1.7mm side mount Red: XL-1606SURC, C965860 Orange: XL-1606UOC, C965861 Green: XL-1606UGC, C965863 Blue: XL-1606UBC, C965865
CHANNEL 0
ISOLATED 3.3V SUPPLY (CH3|ESP)
USB INPUT

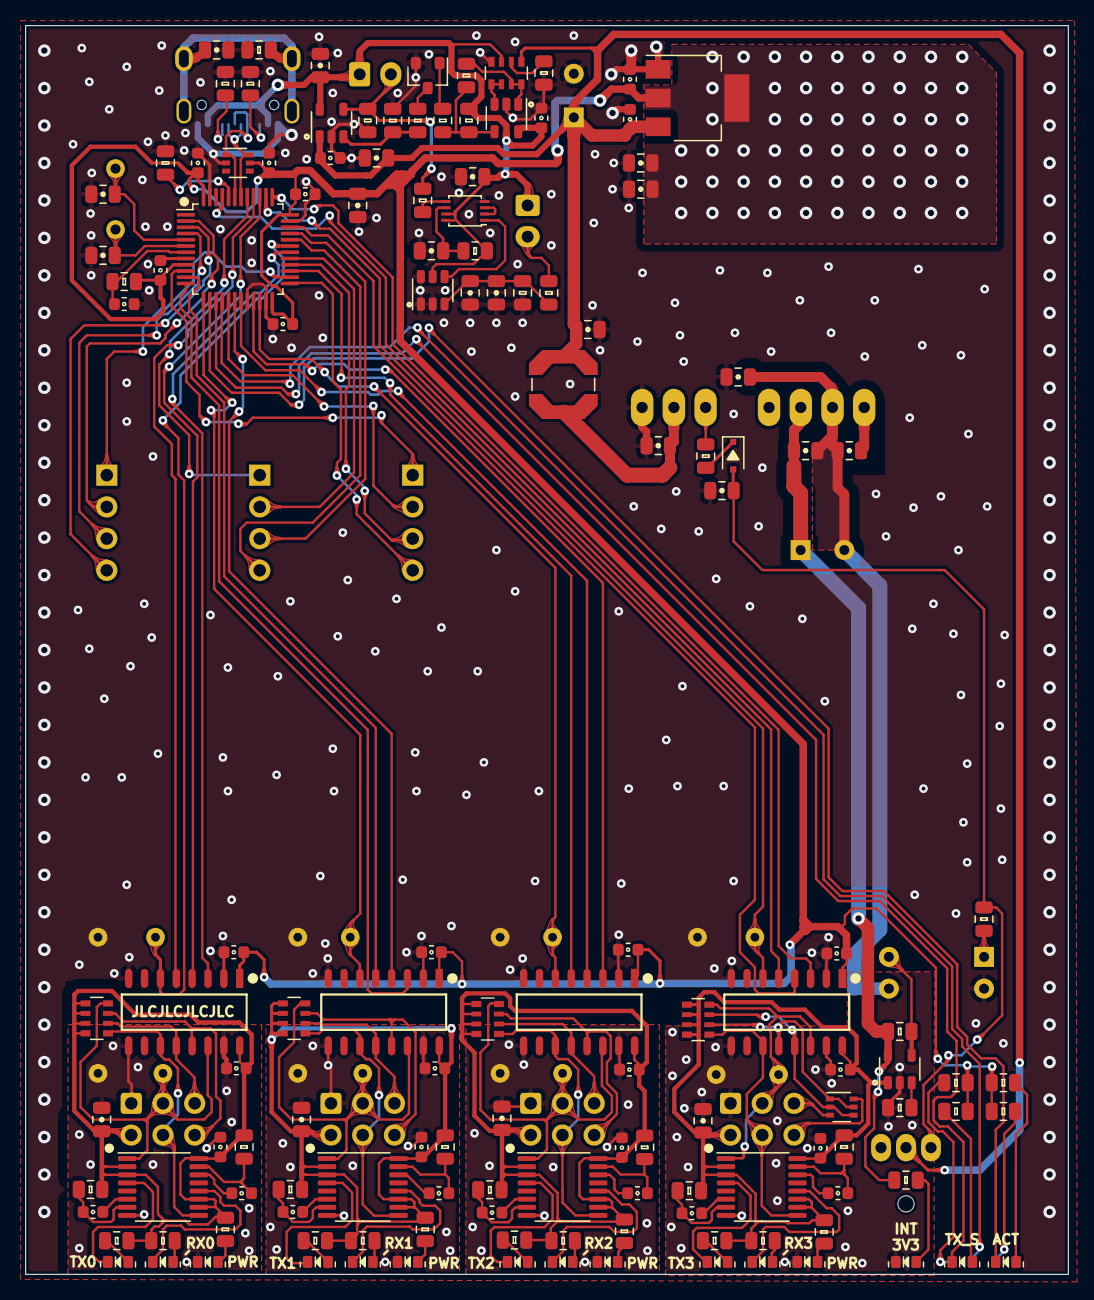
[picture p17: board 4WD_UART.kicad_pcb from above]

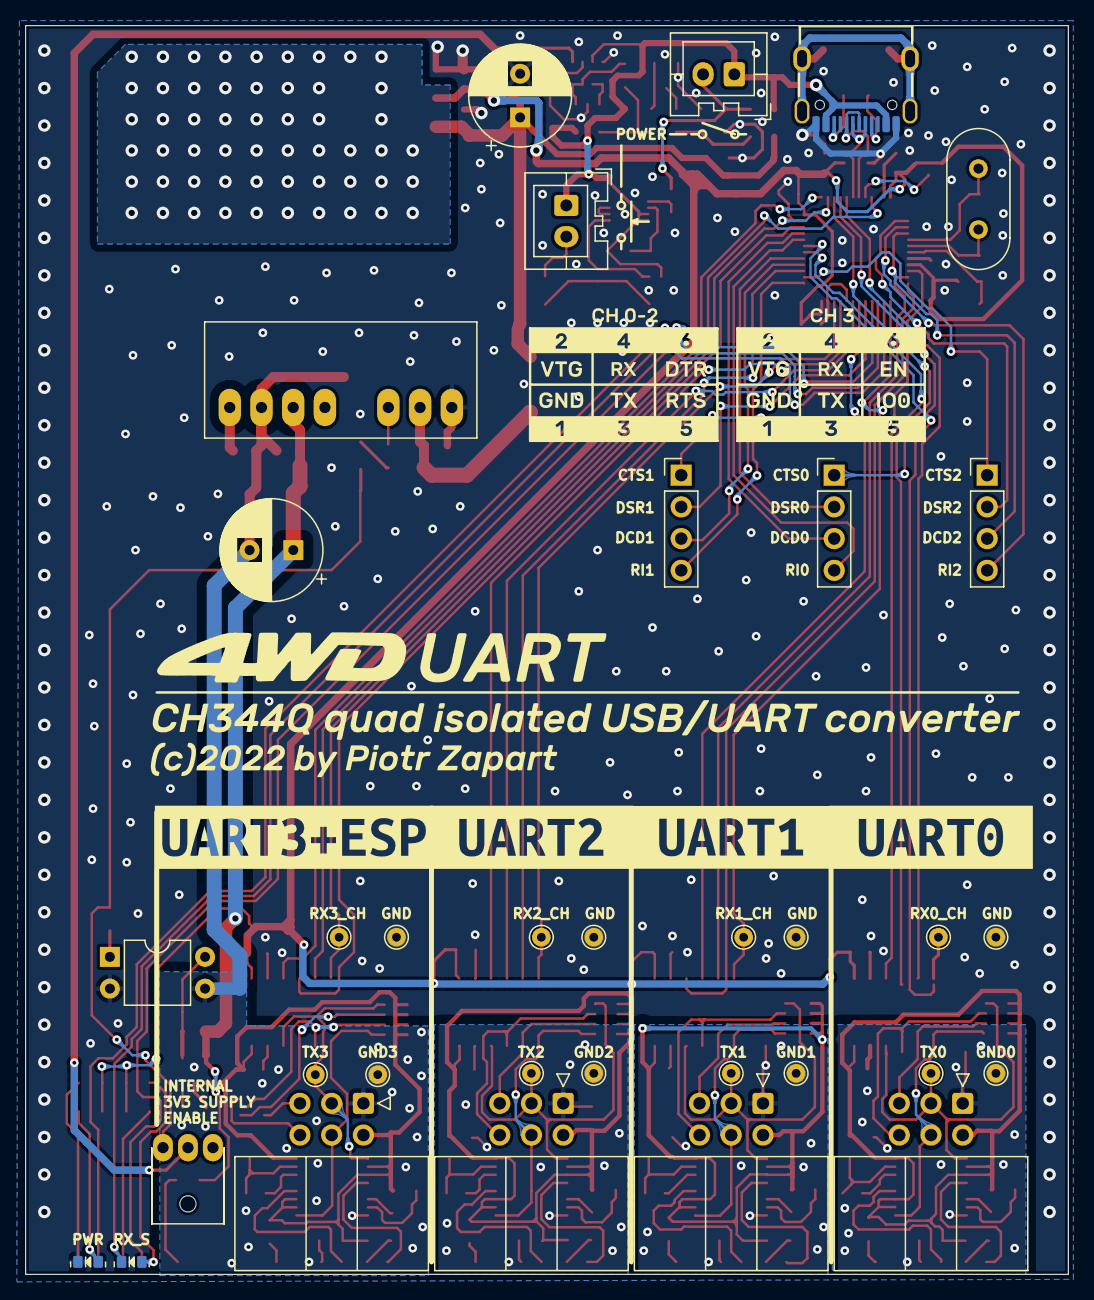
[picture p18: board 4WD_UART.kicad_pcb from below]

Board: 2 copper layers, 83.5 x 100.0 mm, 204 parts (67 on the bottom side), 134 nets.

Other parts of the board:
kibuzzard-62D9AA82: G***; kibuzzard-62D9AA82
kibuzzard-62D9AAED: G***; kibuzzard-62D9AAED
kibuzzard-62D9AB36: G***; kibuzzard-62D9AB36
kibuzzard-62D98D9A: G***; kibuzzard-62D98D9A
kibuzzard-62D98E0C: G***; kibuzzard-62D98E0C
kibuzzard-62D98E43: G***; kibuzzard-62D98E43
kibuzzard-62D98E49: G***; kibuzzard-62D98E49
kibuzzard-62DBE2B6, kibuzzard-62DBE2B6#2: G***; kibuzzard-62DBE2B6
kibuzzard-62DBE2BC, kibuzzard-62DBE2BC#2: G***; kibuzzard-62DBE2BC
kibuzzard-62DBE2C4, kibuzzard-62DBE2C4#2: G***; kibuzzard-62DBE2C4
kibuzzard-62DBE2D9: G***; kibuzzard-62DBE2D9
kibuzzard-62DBE2E2, kibuzzard-62DBE2E2#2: G***; kibuzzard-62DBE2E2
kibuzzard-62DBE4A6, kibuzzard-62DBE4A6#2: G***; kibuzzard-62DBE4A6
kibuzzard-62DBE6A2: G***; kibuzzard-62DBE6A2
kibuzzard-62DBE6B4: G***; kibuzzard-62DBE6B4
kibuzzard-62DBE386: G***; kibuzzard-62DBE386
kibuzzard-62DBE505, kibuzzard-62DBE505#2: G***; kibuzzard-62DBE505
kibuzzard-62DBE511, kibuzzard-62DBE511#2: G***; kibuzzard-62DBE511
kibuzzard-62DBE523, kibuzzard-62DBE523#2: G***; kibuzzard-62DBE523
kibuzzard-62DBE531, kibuzzard-62DBE531#2: G***; kibuzzard-62DBE531
kibuzzard-62DBE545, kibuzzard-62DBE545#2: G***; kibuzzard-62DBE545
kibuzzard-62DC16BA: G***; kibuzzard-62DC16BA
kibuzzard-62DC16CB: G***; kibuzzard-62DC16CB

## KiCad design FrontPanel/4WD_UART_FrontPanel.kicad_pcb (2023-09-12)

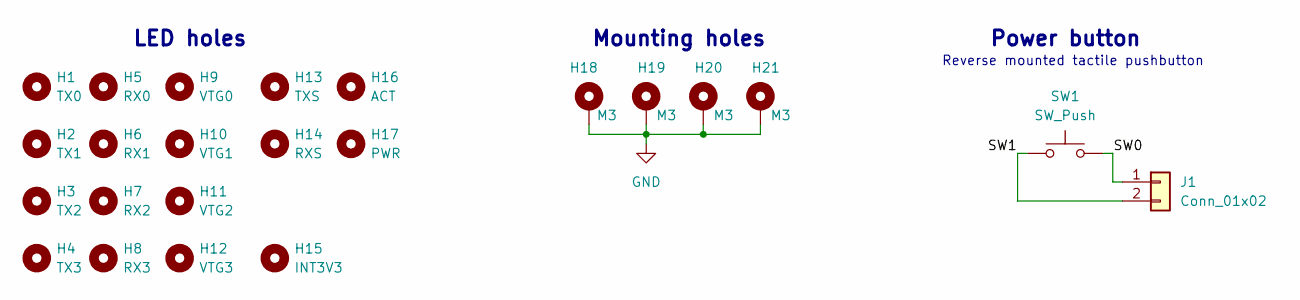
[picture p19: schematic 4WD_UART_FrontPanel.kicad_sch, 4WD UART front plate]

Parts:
H1: TX0; MountingHole_2.2mm_M2_ISO7380
H2: TX1; MountingHole_2.2mm_M2_ISO7380
H3: TX2; MountingHole_2.2mm_M2_ISO7380
H4: TX3; MountingHole_2.2mm_M2_ISO7380
H5: RX0; MountingHole_2.2mm_M2_ISO7380
H6: RX1; MountingHole_2.2mm_M2_ISO7380
H7: RX2; MountingHole_2.2mm_M2_ISO7380
H8: RX3; MountingHole_2.2mm_M2_ISO7380
H9: VTG0; MountingHole_2.2mm_M2_ISO7380
H10: VTG1; MountingHole_2.2mm_M2_ISO7380
H11: VTG2; MountingHole_2.2mm_M2_ISO7380
H12: VTG3; MountingHole_2.2mm_M2_ISO7380
H13: TXS; MountingHole_2.2mm_M2_ISO7380
H14: RXS; MountingHole_2.2mm_M2_ISO7380
H15: INT3V3; MountingHole_2.2mm_M2_ISO7380
H16: ACT; MountingHole_2.2mm_M2_ISO7380
H17: PWR; MountingHole_2.2mm_M2_ISO7380
H18, H19, H20, H21: M3; MountingHole_3.2mm_M3_Pad_Via
J1: Conn_01x02; PinHeader_1x02_P2.54mm_Vertical_SMD_Pin1Left
SW1: SW_Push; SW_Push_1P1T_NO_6x6mm_H9.5mm_reverse_mount

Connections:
/SW0: J1.1, SW1.2
/SW1: J1.2, SW1.1
GND: H18.1, H19.1, H20.1, H21.1

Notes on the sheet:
Reverse mounted tactile pushbutton
Mounting holes
LED holes
Power button

Board: 2 copper layers, 72 parts (2 on the bottom side), 3 nets, no tracks yet.

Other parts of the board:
kibuzzard-62D9AA82: G***; kibuzzard-62D9AA82
kibuzzard-62DBDE6B, kibuzzard-62DBDE6B#2, kibuzzard-62DBDE6B#3, kibuzzard-62DBDE6B#4: G***; kibuzzard-62DBDE6B
kibuzzard-62DBDE64: G***; kibuzzard-62DBDE64
kibuzzard-62DBE0FA: G***; kibuzzard-62DBE0FA
kibuzzard-62DBE1C8: G***; kibuzzard-62DBE1C8
kibuzzard-62DBE1D1: G***; kibuzzard-62DBE1D1
kibuzzard-62DBE1D8: G***; kibuzzard-62DBE1D8
kibuzzard-62DBE1FE: G***; kibuzzard-62DBE1FE
kibuzzard-62DBE2B6, kibuzzard-62DBE2B6#2: G***; kibuzzard-62DBE2B6
kibuzzard-62DBE2BC, kibuzzard-62DBE2BC#2: G***; kibuzzard-62DBE2BC
kibuzzard-62DBE2C4, kibuzzard-62DBE2C4#2: G***; kibuzzard-62DBE2C4
kibuzzard-62DBE2D9: G***; kibuzzard-62DBE2D9
kibuzzard-62DBE2E2, kibuzzard-62DBE2E2#2: G***; kibuzzard-62DBE2E2
kibuzzard-62DBE4A6, kibuzzard-62DBE4A6#2: G***; kibuzzard-62DBE4A6
kibuzzard-62DBE6A2: G***; kibuzzard-62DBE6A2
kibuzzard-62DBE6B4: G***; kibuzzard-62DBE6B4
kibuzzard-62DBE020: G***; kibuzzard-62DBE020
kibuzzard-62DBE071: G***; kibuzzard-62DBE071
kibuzzard-62DBE083: G***; kibuzzard-62DBE083
kibuzzard-62DBE135: G***; kibuzzard-62DBE135
kibuzzard-62DBE386: G***; kibuzzard-62DBE386
kibuzzard-62DBE505, kibuzzard-62DBE505#2: G***; kibuzzard-62DBE505
kibuzzard-62DBE511, kibuzzard-62DBE511#2: G***; kibuzzard-62DBE511
kibuzzard-62DBE523, kibuzzard-62DBE523#2: G***; kibuzzard-62DBE523
kibuzzard-62DBE531, kibuzzard-62DBE531#2: G***; kibuzzard-62DBE531
kibuzzard-62DBE545, kibuzzard-62DBE545#2: G***; kibuzzard-62DBE545
kibuzzard-62DBE989: G***; kibuzzard-62DBE989
kibuzzard-62DC0E3F: G***; kibuzzard-62DC0E3F
kibuzzard-62DC0E09: G***; kibuzzard-62DC0E09
kibuzzard-62DC0E10: G***; kibuzzard-62DC0E10
kibuzzard-62DC0E19: G***; kibuzzard-62DC0E19
kibuzzard-62DC0E21: G***; kibuzzard-62DC0E21
kibuzzard-62DC0E29: G***; kibuzzard-62DC0E29
kibuzzard-62DC0E32: G***; kibuzzard-62DC0E32
kibuzzard-62DC0E38: G***; kibuzzard-62DC0E38
kibuzzard-62DC0460: G***; kibuzzard-62DC0460

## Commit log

2022-09-14 design files added
    [4WD_UART.kicad_pcb, 4WD_UART.kicad_sch, 4WD_UART_BackPanel.kicad_pcb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]
2023-09-11 Convert to newer kicad version by saving in kicad-7.0.6
    [4WD_UART.kicad_pcb, 4WD_UART.kicad_sch, 4WD_UART_BackPanel.kicad_pcb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]
